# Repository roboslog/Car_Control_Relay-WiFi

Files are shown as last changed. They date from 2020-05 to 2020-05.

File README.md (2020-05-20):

# Car_Control_Relay-WiFi
 Car ignition control relay board

This Car ignition control relay board is very useful to control car to drive the relay with a 3.3v signal of esp8266. Relay connects & disconnects 12v supply of car battery to various components of bike. We have used LM2950 5V voltage regulator to drop down 12v DC supply to 5v DC supply. capacitor added on outer terminal to decrease the noise.

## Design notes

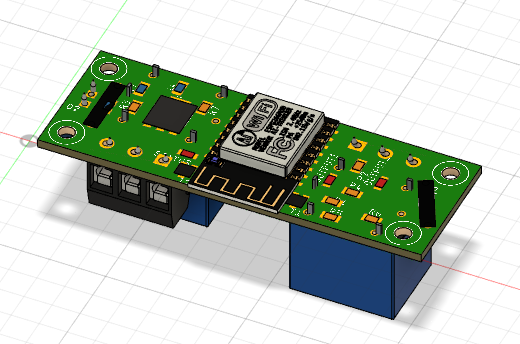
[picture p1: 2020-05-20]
Screenshot 2020-05-20 at 21.15.14.png

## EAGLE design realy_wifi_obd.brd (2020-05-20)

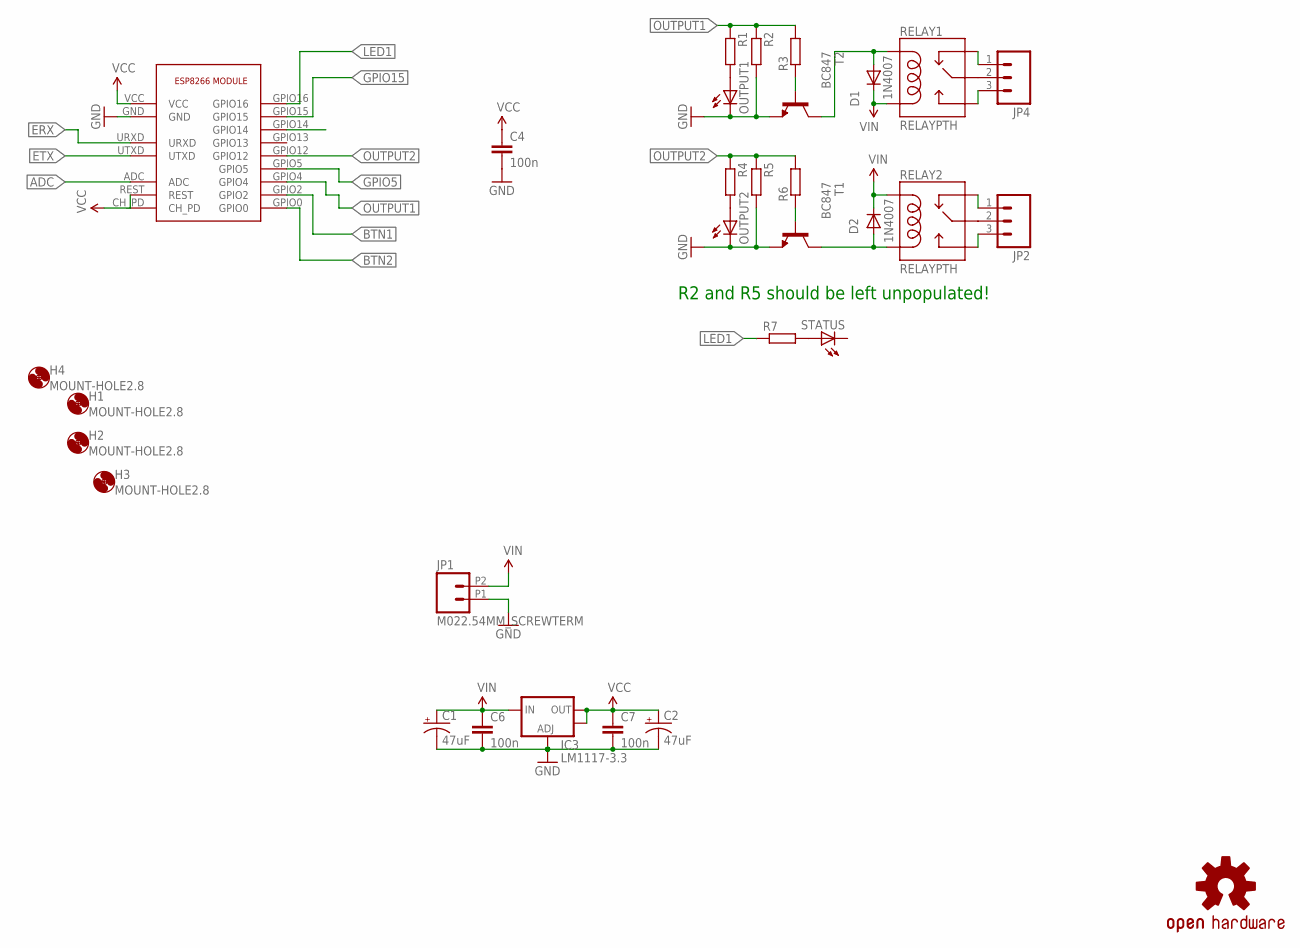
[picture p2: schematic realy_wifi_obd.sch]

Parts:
C1, C2: 47uF; PANASONIC_D
C4, C6, C7: 100n; C0805K
D1, D2: 1N4942; DO41-10
ESP8266: ESP8266ESP-07; ESP-12
H1, H2, H3, H4: MOUNT-HOLE2.8; 2,8
IC3: LM1117-3.3; SOT223
JP1: M022.54MM_SCREWTERM; 1X02_2.54_SCREWTERM
JP2, JP4: M03-SCREW-5MM; SCREWTERMINAL-5MM-3
LOGO1: OSHW-LOGOL; OSHW-LOGO-L
OUTPUT1, OUTPUT2: LEDCHIP-LED0805; CHIP-LED0805
R1, R2, R3, R4, R5, R6, R7: SMARTPRJ_R-EU_M0805; SMARTPRJ_M0805
RELAY1, RELAY2: RELAYPTH; SRD-05VDC-SL-C
STATUS: LEDCHIP-LED0805; CHIP-LED0805
T1, T2: BC847; SOT23

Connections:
ADC: ESP8266.ADC
BTN1: ESP8266.GPIO2
BTN2: ESP8266.GPIO0
DHT22: ESP8266.GPIO14
ERX: ESP8266.URXD
ETX: ESP8266.UTXD
GND: C1.-, C2.-, C4.2, C6.2, C7.2, ESP8266.GND, IC3.1 (ADJ), JP1.P1 (1), OUTPUT1.C, OUTPUT2.C, R2.2, R5.2, T1.2 (E), T2.2 (E)
GPIO5: ESP8266.GPIO5
GPIO15: ESP8266.GPIO15
LED1: ESP8266.GPIO16, R7.1
unnamed: D2.A, RELAY2.COIL0, T1.3 (C)
unnamed: D1.A, RELAY1.COIL1, T2.3 (C)
unnamed: JP2.2, RELAY2.SWCOMMON
unnamed: JP4.2, RELAY1.SWCOMMON
unnamed: JP4.1, RELAY1.SWCLOSED (SWCLOSE)
unnamed: JP4.3, RELAY1.SWOPEN
unnamed: JP2.3, RELAY2.SWOPEN
unnamed: JP2.1, RELAY2.SWCLOSED (SWCLOSE)
unnamed: R3.1, T2.1 (B)
unnamed: R6.1, T1.1 (B)
unnamed: OUTPUT2.A, R4.2
unnamed: R7.2, STATUS.A
unnamed: OUTPUT1.A, R1.2
OUTPUT1: ESP8266.GPIO4, R1.1, R2.1, R3.2
OUTPUT2: ESP8266.GPIO12, R4.1, R5.1, R6.2
VCC: C2.+, C4.1, C7.1, ESP8266.CH_PD, ESP8266.REST, ESP8266.VCC, IC3.2 (OUT), IC3.4 (OUT)
VIN: C1.+, C6.1, D1.C, D2.C, IC3.3 (IN), JP1.P2 (2), RELAY1.COIL0, RELAY2.COIL1

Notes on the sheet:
1N4007
R2 and R5 should be left unpopulated!

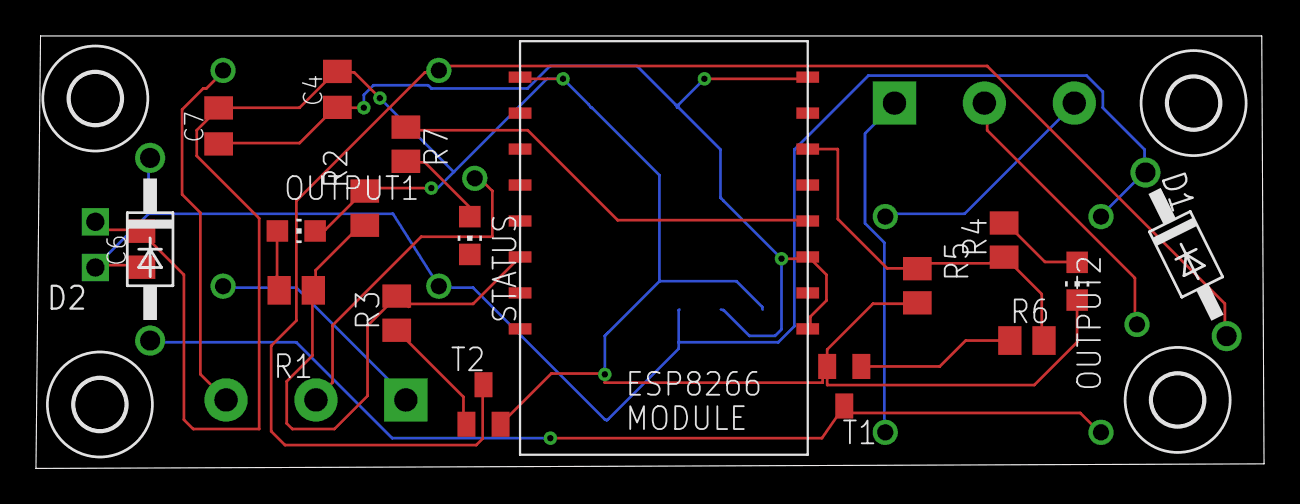
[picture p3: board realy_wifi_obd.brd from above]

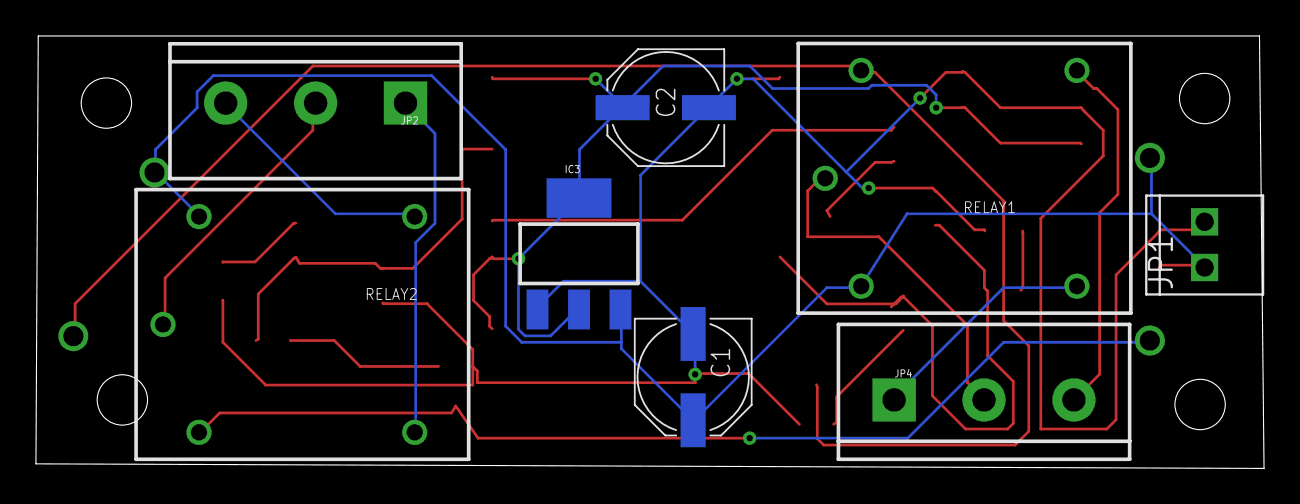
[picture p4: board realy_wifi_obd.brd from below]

Board: 2 copper layers, 68.3 x 24.1 mm, 31 parts (8 on the bottom side), 19 nets.

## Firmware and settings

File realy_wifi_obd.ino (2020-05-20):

#include <ESP8266WiFi.h>
#define LED D1
#define LED2 D0
const char* ssid = "Robo";
const char* password = "lopklopk";
unsigned char status_led=0;
unsigned char status_led2=0;
//IPAddress ip(192, 168, 43, 238); //set static ip
//IPAddress gateway(192, 168, 0, 1); //set getteway
IPAddress subnet(255, 255, 255, 0);//set subnet
WiFiServer server(80);

void setup() {
  Serial.begin(115200);
  pinMode(LED, OUTPUT);
    pinMode(LED2, OUTPUT);
  Serial.println();
  Serial.println();
  Serial.print("Connecting to ");
  Serial.println(ssid);
 // WiFi.config(ip, gateway, subnet);
  
  WiFi.begin(ssid, password);
  while (WiFi.status() != WL_CONNECTED) 
  {
    delay(500);
    Serial.print(".");
  }
  Serial.println("");
  Serial.println("WiFi connected");
  server.begin();
  Serial.println("Server started");
  Serial.println(WiFi.localIP());
}

void loop() {
  WiFiClient client = server.available();
  if (!client) {
    return;
  }
  
  Serial.println("new client");
  while(!client.available())
  {
    
    delay(1);
    
  }
  String req = client.readStringUntil('\r');
  Serial.println(req);
  client.flush();
  if (req.indexOf("/ledoff") != -1)
  {
    status_led=0;   
    digitalWrite(LED,LOW);
    Serial.println("LED OFF");
  }
  else if(req.indexOf("/ledon") != -1)
  {
    status_led2=1;
    digitalWrite(LED,HIGH);
    Serial.println("LED ON");
  }
  
  if (req.indexOf("/led2off") != -1)
  {
    status_led2=0;   
    digitalWrite(LED2,LOW);
    Serial.println("LED2 OFF");
  }
  else if(req.indexOf("/led2on") != -1)
  {
    status_led=1;
    digitalWrite(LED2,HIGH);
    Serial.println("LED2 ON");
  }
  String web = "HTTP/1.1 200 OK\r\nContent-Type: text/html\r\n\r\n";
  web += "<html>\r\n";
  web += "<body>\r\n";
  web += "<h1>LED Status</h1>\r\n";
  web += "<p>\r\n";
  if(status_led==1)
      web += "LED On\r\n";
  else
      web += "LED Off\r\n";
       if(status_led2==1)
      web += "LED2 On\r\n";
  else
      web += "LED2 Off\r\n";
  web += "</p>\r\n";
  web += "</p>\r\n";
  web += "<a href=\"/ledon\">\r\n";
  web += "<button>LED On</button >\r\n";

    web += "<a href=\"/led2on\">\r\n";
  web += "<button>LED2 On</button >\r\n";
  web += "</a>\r\n";
  web += "</p>\r\n";
  
  web += "<a href=\"/ledoff\">\r\n";
  web += "<button>LED Off</button >\r\n";
  
  web += "<a href=\"/led2off\">\r\n";
  web += "<button>LED2 Off</button >\r\n";
  web += "</a>\r\n";
  
  web += "</body>\r\n";
  web += "</html>\r\n";
  
  client.print(web);
}

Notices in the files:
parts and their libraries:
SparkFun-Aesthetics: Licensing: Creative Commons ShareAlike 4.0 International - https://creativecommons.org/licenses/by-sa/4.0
